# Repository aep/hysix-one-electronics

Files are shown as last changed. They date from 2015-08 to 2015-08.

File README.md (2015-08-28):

Hysix One
=================

An Arduino compatible long runtime GSM sensor board.
The board is designed for use cases where the MCU remains mostly idle, then switches on in regular intervals to collect data and talk to the internet.

Features
-----
- Two external sensors with each 2 data lines can be connected and powered from the board.
- GSM module can be powered off completely independant from system power
- Ultra low power RTC switches entire board power (except RTC itself) for very long idle runtime.
- Arduino IDE compatible.

Mappings
-----
<table>
    <tr>
        <td>SIM800L RX</td>
        <td>7</td>
        <td></td>
    </tr>
    <tr>
        <td>SIM800L TX</td>
        <td>8</td>
        <td></td>
    </tr>
    <tr>
        <td>SIM800L Enable Power</td>
        <td>9</td>
        <td>switch power to the SIM</td>
    </tr>
    <tr>
        <td>LDO_ENABLE</td>
        <td>10</td>
        <td>enable line for the LDO supplying the avr</td>
    </tr>
    <tr>
        <td>BATTER_METER</td>
        <td>A0</td>
        <td>raw battery voltage divided by two</td>
    </tr>
    <tr>
        <td>BATTER_METER_ENABLE</td>
        <td>2</td>
        <td>pull low to enable voltage divider</td>
    </tr>
    <tr>
        <td>SENSOR PINS</td>
        <td>3,4,5,6,</td>
        <td>data lines on the sensor connectors </td>
    </tr>
    <tr>
        <td>RTC</td>
        <td>I2C</td>
        <td>RTC is on standard I2C bus</td>
    </tr>
</table>

Stats
-----

<table>
    <tr>
        <td>Peak Power</td>
        <td>200mA</td>
    </tr>
    <tr>
        <td>Idle Power</td>
        <td>11mA</td>
    </tr>
    <tr>
        <td>RTC Standby Power</td>
        <td> &lt; 1uA </td>
    </tr>
</table>

RTC
-----

The RTC is a DS134X TDFN at I2C address 0x68 that switches the entire system off, keeps a clock, and switches it back on at a desired time.
In the default solder jumper configuration, it has INTB connected to LDO enable, inverted by a transistor,
so that high means LDO is on, which is the default in shipping state.
The avr remains powered until the RTC gets interupt enable set.

Visual
-------
size aprox 5x5cm
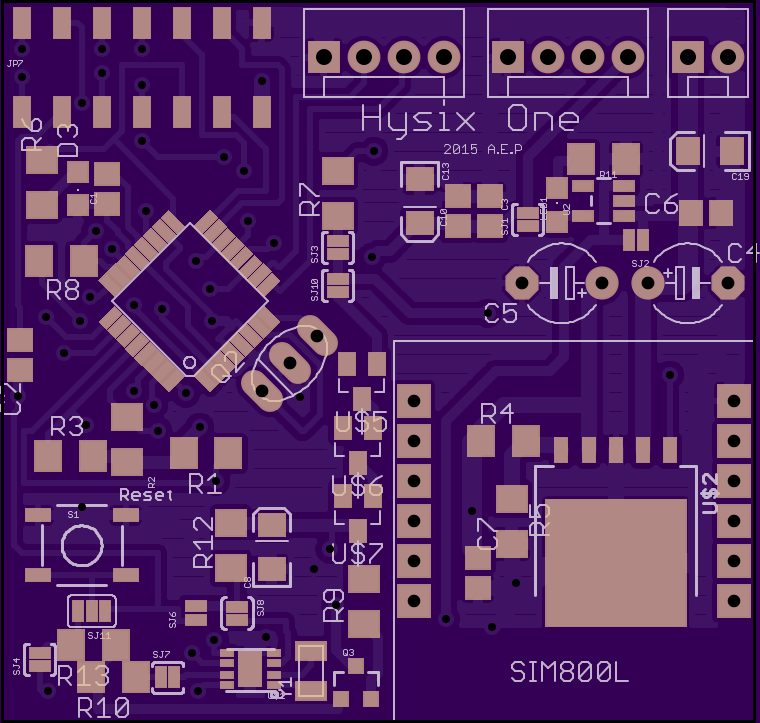
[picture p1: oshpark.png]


Design Notes
-------

- The Diodes in front of the RTC are supposed to drop voltage from BAT to max 5V. There is no extra regulator, because the RTC is fairly tolerant.
- There's no routing to the reset pin of the SIM800. To use the FONA library, it needs to have the reset code removed.
- The reset button turns the avr ON when the RTC switched the system off. Make sure to reset the RTC fairly early so that system stays on after releasing the button.

License
-------
http://opensource.org/licenses/MIT

Bugs
------

1. Forgot to route reset without the arduino cap.
   To burn a bootloader, reset needs to be soldered onto the MCU side of R2 instead of using the pin header.
   During normal arduino 'uploading', the pins will work fine.

2. The connector parts in the scheme don't actually fit. Ignore them and use bare pin headers.

3. LDO_ENABLE is a wasted pin. The RTC is already enabling the LDO. It's probably a good idea to leave SJ4 open.

4. Forgot resistors for RX on the SIM800. The SIM800 is speced at max 3.1V TTL. Works fine, but...

5. The package for the Crystal is wrong. It's an SMD package, but the layout is for through hole.
   It fits sort of anyway. Originally i intended to run the avr without crystal, but the factory tunings for
   the internal clock are for 3.3V, not for 5V. A nightmare not worth it.

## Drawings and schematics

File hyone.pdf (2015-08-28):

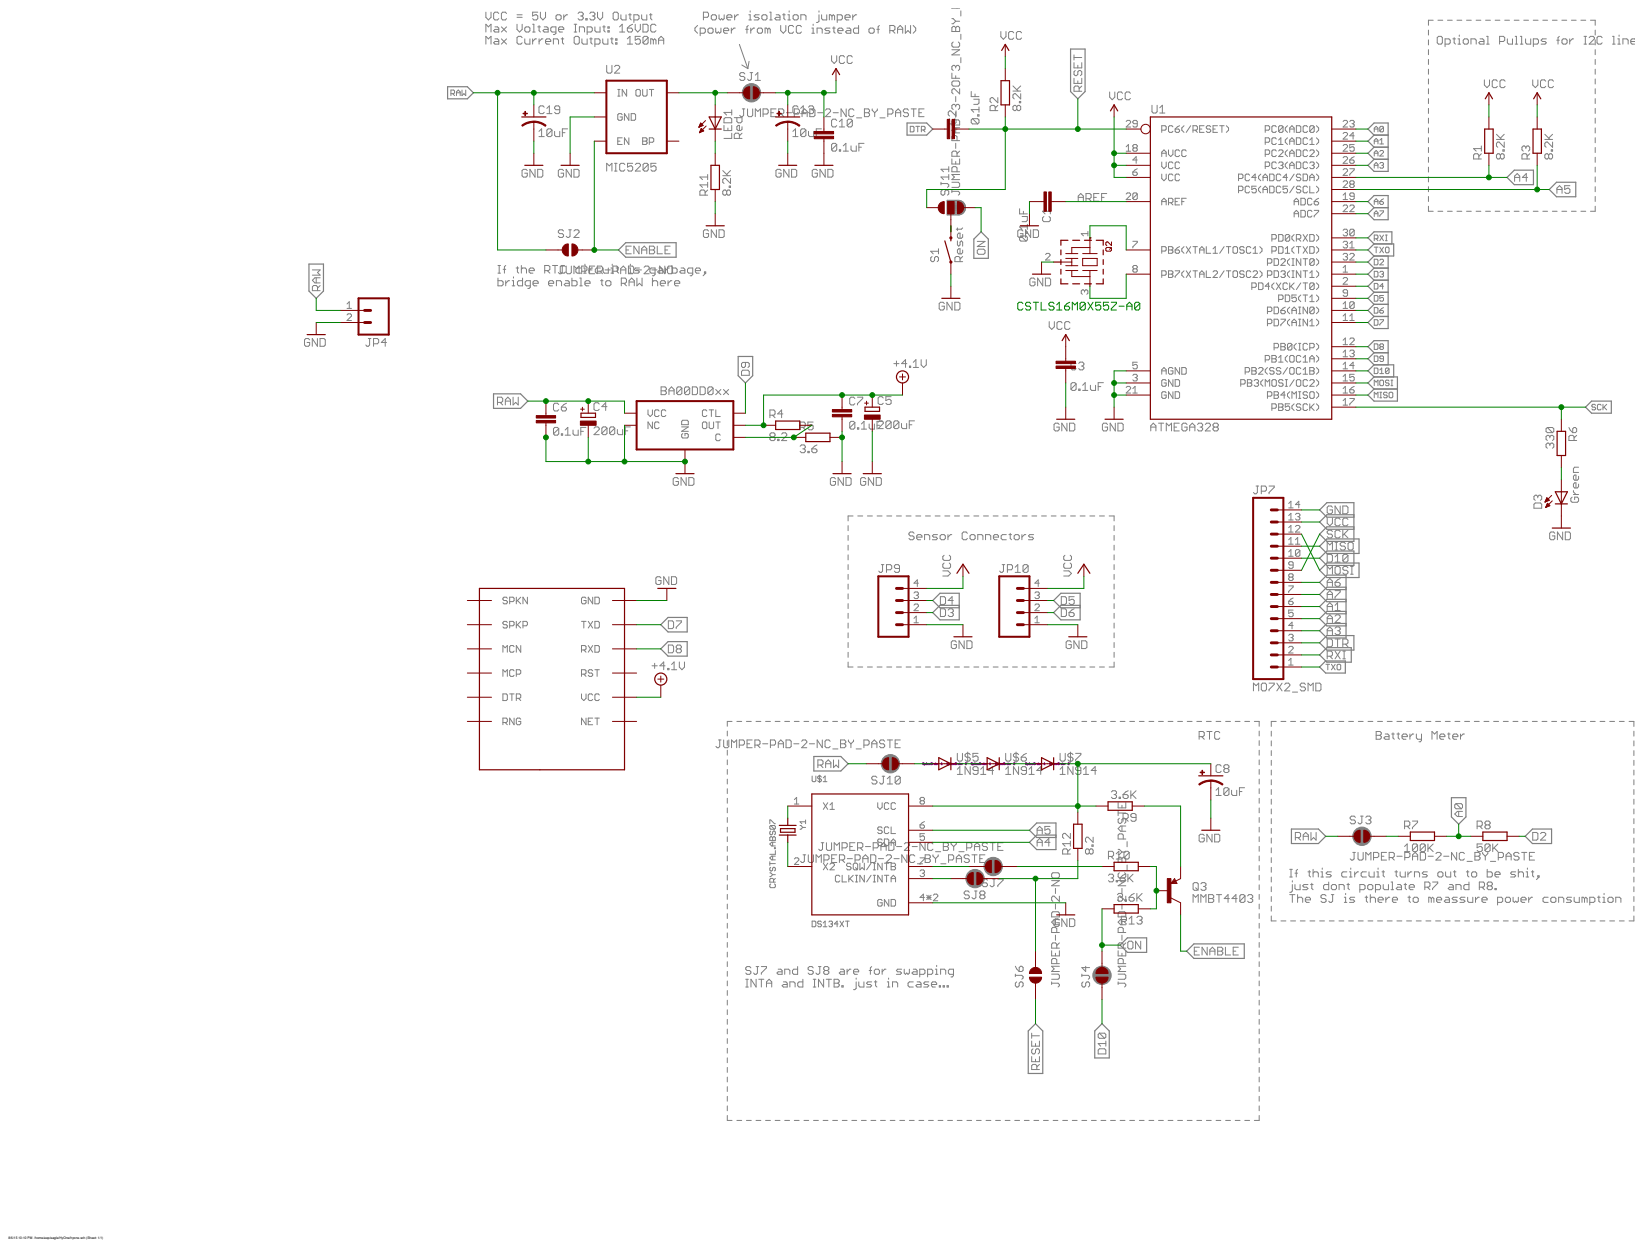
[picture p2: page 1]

8/6/15 10:10 PM /home/aep/eagle/HyOne/hyone.sch (Sheet: 1/1)

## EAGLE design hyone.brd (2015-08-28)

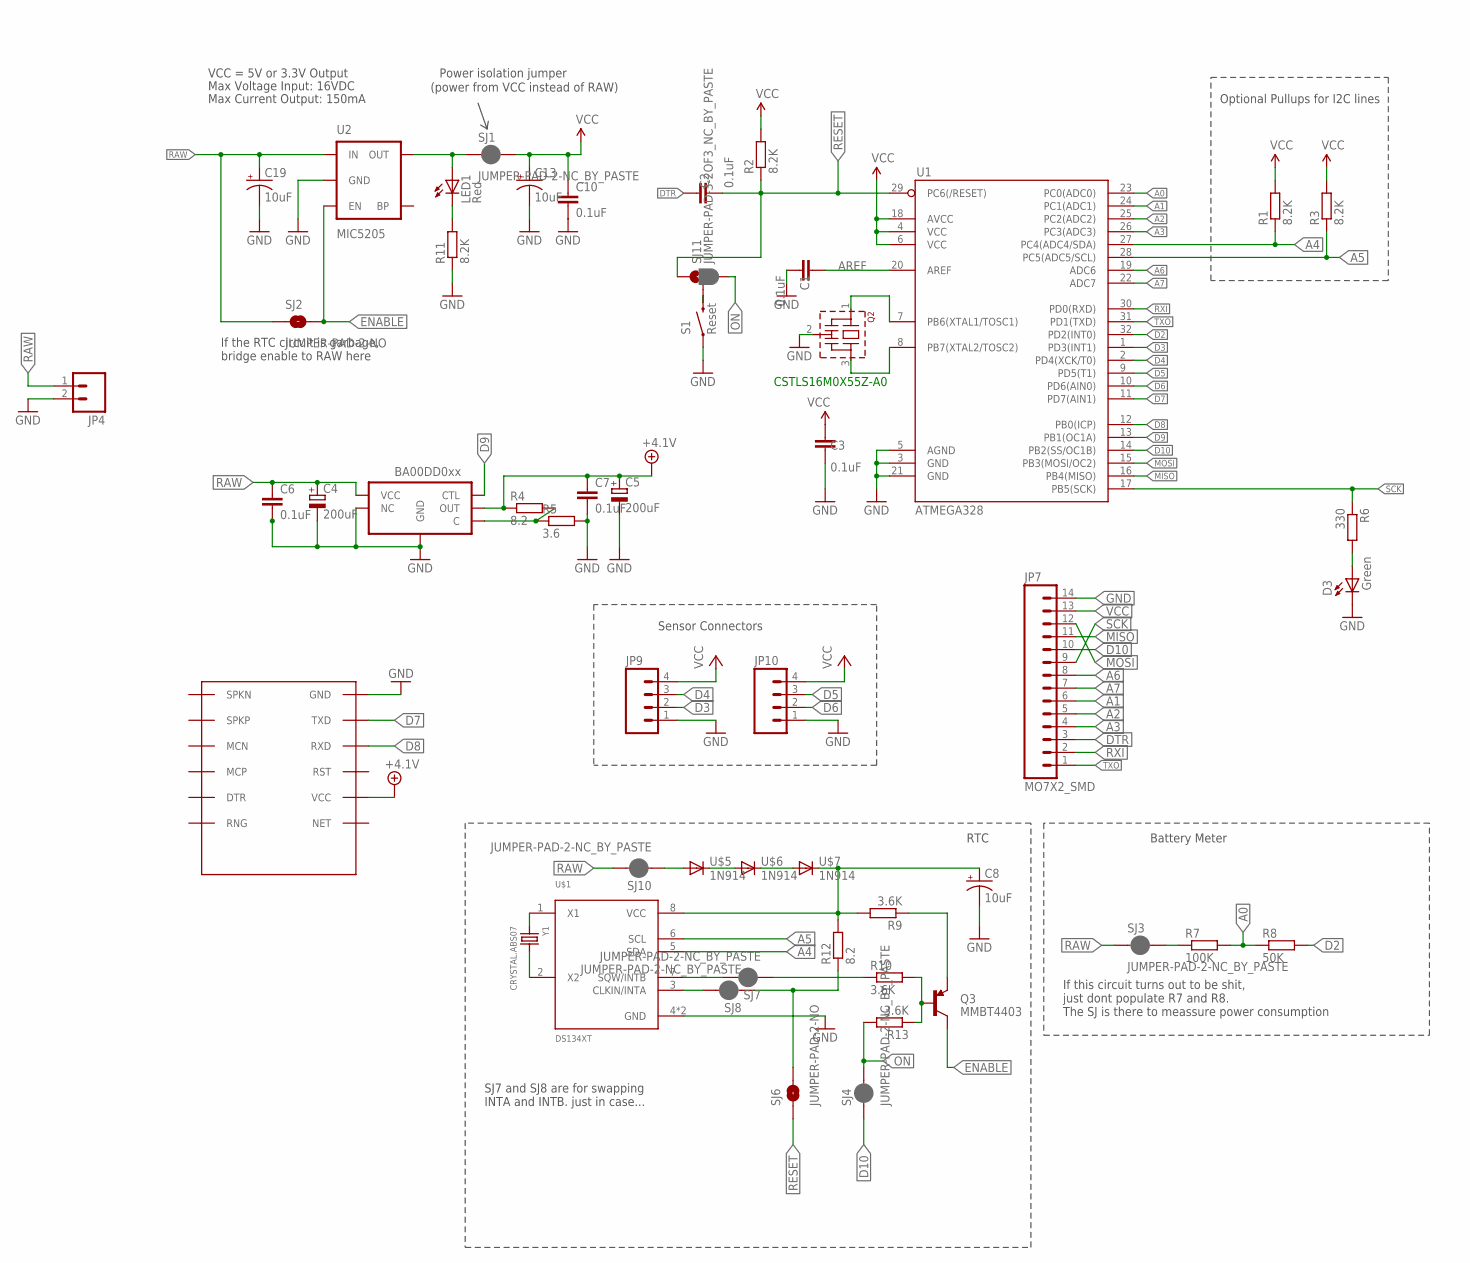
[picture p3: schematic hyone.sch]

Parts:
C1, C2, C3, C6, C7, C10: 0.1uF; C0805
C4, C5: 200uF; E5-5
C8, C13, C19: 10uF; EIA3216
D3: Green; CHIPLED_0805
JP4: M02POLAR; MOLEX-1X2
JP7: MO7X2_SMD; 2X7_SMD
JP9, JP10: M04POLAR; MOLEX-1X4
LED1: Red; CHIPLED_0805
Q2: CSTLS_X
Q3: MMBT4403; SOT23-3
R1, R2, R3, R11: 8.2K; R1206
R4, R12: 8.2; R1206
R5: 3.6; R1206
R6: 330; R1206
R7: 100K; R1206
R8: 50K; R1206
R9, R10, R13: 3.6K; R1206
S1: Reset; TACTILE-SWITCH-SMD-ALT01
SJ1, SJ3, SJ4, SJ7, SJ8, SJ10: JUMPER-PAD-2-NC_BY_PASTE; PAD-JUMPER-2-NC_BY_PASTE_YES_SILK
SJ2, SJ6: JUMPER-PAD-2-NO; PAD-JUMPER-2-NO_NO_SILK
SJ11: JUMPER-PAD-3-2OF3_NC_BY_PASTE; PAD-JUMPER-3-2OF3_NC_BY_PASTE_YES_SILK_FULL_BOX
U1: ATMEGA328; TQFP32-08
U2: MIC5205; SOT23-5
U$1: DS134XT; TDFN-8
U$2: BA00DD0XX; HRP5
U$4: SIM800L; SIM-CORE
U$5, U$6, U$7: 1N914; SOT23
Y1: CRYSTAL.ABS07; ABS07

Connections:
123123: SJ10.1, U$5.1 (A)
+4.1V: C5.+, C7.1, R4.1, U$2.4 (OUT), U$4.VCC
A0: R7.2, R8.1, U1.23 (PC0(ADC0))
A1: JP7.6, U1.24 (PC1(ADC1))
A2: JP7.5, U1.25 (PC2(ADC2))
A3: JP7.4, U1.26 (PC3(ADC3))
A4: R1.1, U1.27 (PC4(ADC4/SDA)), U$1.5 (SDA)
A5: R3.1, U1.28 (PC5(ADC5/SCL)), U$1.6 (SCL)
A6: JP7.8, U1.19 (ADC6)
A7: JP7.7, U1.22 (ADC7)
AREF: C1.2, U1.20 (AREF)
D2: R8.2, U1.32 (PD2(INT0))
D3: JP9.2, U1.1 (PD3(INT1))
D4: JP9.3, U1.2 (PD4(XCK/T0))
D5: JP10.3, U1.9 (PD5(T1))
D6: JP10.2, U1.10 (PD6(AIN0))
D7: U1.11 (PD7(AIN1)), U$4.TXD
D8: U1.12 (PB0(ICP)), U$4.RXD
D9: U1.13 (PB1(OC1A)), U$2.1 (CTL)
D10: JP7.10, SJ4.1, U1.14 (PB2(SS/OC1B))
DTR: C2.2, JP7.3
ENABLE: Q3.3 (C), SJ2.2, U2.3 (EN)
GND: C1.1, C3.1, C4.-, C5.-, C6.2, C7.2, C8.C (-), C10.2, C13.C (-), C19.C (-), D3.C, JP4.2, JP7.14, JP9.1, JP10.1, Q2.2 (VSS), R5.2, R11.1, S1.1, S1.2 (1), U1.3 (GND), U1.5 (AGND), U1.21 (GND), U2.2 (GND), U$1.4 (GND), U$1.EP (GND), U$2.3 (NC), U$2.6 (GND), U$4.GND
MISO: JP7.11, U1.16 (PB4(MISO))
MOSI: JP7.12, U1.15 (PB3(MOSI/OC2))
unnamed: Q2.1, U1.7 (PB6(XTAL1/TOSC1))
unnamed: Q2.3, U1.8 (PB7(XTAL2/TOSC2))
unnamed: LED1.A, SJ1.1, U2.5 (OUT)
unnamed: LED1.C, R11.2
unnamed: R4.2, R5.1, U$2.5 (C)
unnamed: U$1.1 (X1), Y1.1
unnamed: D3.A, R6.2
unnamed: U$1.2 (X2), Y1.2
unnamed: Q3.2 (E), R9.1
unnamed: Q3.1 (B), R10.2, R13.1
unnamed: C8.A (+), R9.2, R12.2, U$1.8 (VCC), U$7.3 (C)
unnamed: R10.1, SJ7.1
unnamed: R7.1, SJ3.2
unnamed: S1.3 (2), S1.4 (2), SJ11.2
unnamed: R12.1, SJ6.2, SJ8.1
unnamed: SJ7.2, U$1.7 (SQW/INTB)
unnamed: SJ8.2, U$1.3 (CLKIN/INTA)
unnamed: U$5.3 (C), U$6.1 (A)
unnamed: U$6.3 (C), U$7.1 (A)
ON: R13.2, SJ4.2, SJ11.3
RAW: C4.+, C6.1, C19.A (+), JP4.1, SJ2.1, SJ3.1, SJ10.2, U2.1 (IN), U$2.2 (VCC)
RESET: C2.1, R2.1, SJ6.1, SJ11.1, U1.29 (PC6(/RESET))
RXI: JP7.2, U1.30 (PD0(RXD))
SCK: JP7.9, R6.1, U1.17 (PB5(SCK))
TXO: JP7.1, U1.31 (PD1(TXD))
VCC: C3.2, C10.1, C13.A (+), JP7.13, JP9.4, JP10.4, R1.2, R2.2, R3.2, SJ1.2, U1.4 (VCC), U1.6 (VCC), U1.18 (AVCC)

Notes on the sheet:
Max Voltage Input: 16VDC
Max Current Output: 150mA
VCC = 5V or 3.3V Output
Optional Pullups for I2C lines
RTC
Power isolation jumper
(power from VCC instead of RAW)
Battery Meter
Sensor Connectors
If the RTC circuit is garbage, bridge enable to RAW here
If this circuit turns out to be shit, just dont populate R7 and R8. The SJ is there to meassure power consumption
SJ7 and SJ8 are for swapping INTA and INTB. just in case...
CSTLS16M0X55Z-A0

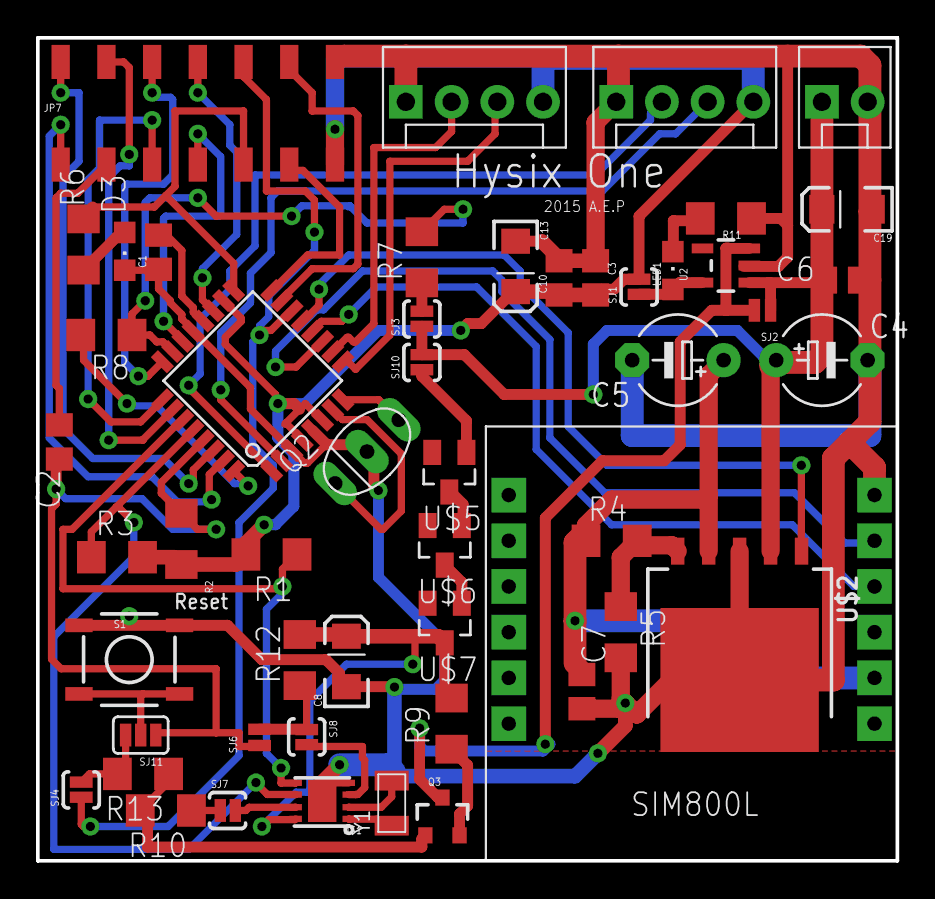
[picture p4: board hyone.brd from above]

Board: 2 copper layers, 47.8 x 45.7 mm, 52 parts (1 on the bottom side), 51 nets.

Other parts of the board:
U$3: OSHW-LOGOS; OSHW-LOGO-S

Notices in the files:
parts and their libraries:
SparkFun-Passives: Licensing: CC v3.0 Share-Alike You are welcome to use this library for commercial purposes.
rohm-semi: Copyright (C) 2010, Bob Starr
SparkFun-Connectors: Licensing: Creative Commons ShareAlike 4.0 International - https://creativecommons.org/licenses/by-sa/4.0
